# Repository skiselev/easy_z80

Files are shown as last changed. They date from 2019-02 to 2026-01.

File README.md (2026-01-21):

# Easy Z80
An easy to build Zilog Z80 based single board computer

## Table of Contents
* [Introduction](#introduction)
* [Specifications](#specifications)
* [Hardware Documentation](#hardware-documentation)
  * [Schematic and PCB Layout](#schematic-and-pcb-layout)
  * [Connectors and Jumpers](#connectors-and-jumpers)
  * [Bill of Materials](#bill-of-materials)
* [Firmware Documentation](#firmware-documentation)
  * [BIOS and OS](#bios-and-os)
  * [SPLD Fuse Map](#spld-fuse-map)
* [Release Notes](#release-notes)
  * [Changes](#changes)
  * [Known Issues](#known-issues)
  * [Wishlist](#wishlist)

## Introduction
My son Max asked me what it takes to build a computer, and whether or not he can design and build one himself. This project is our attempt to design and build a simple, easy to understand, yet capable single board computer.
It reuses the same memory paging mechanism I've implemented in Zeta SBC V2. It uses the Zilog Z80 SIO/O, Z80 CTC peripheral ICs, and implements daisy chain mode 2 interrupt configuration.

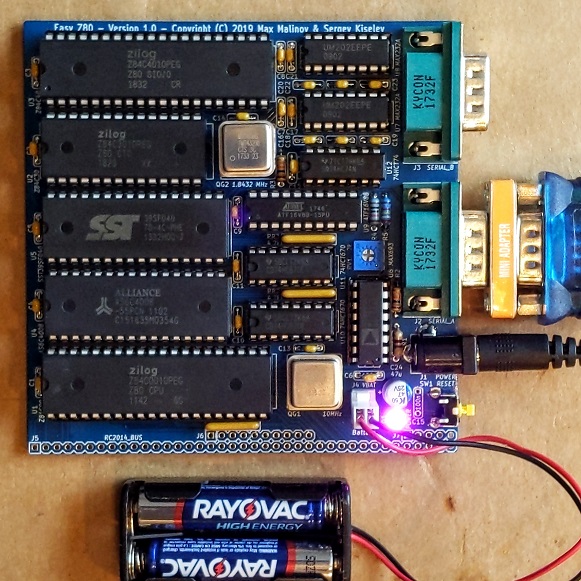
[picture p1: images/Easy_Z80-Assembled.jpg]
Easy Z80 PCB Rendering


## Specifications
* Processor: Zilog Z80 CPU (CMOS version - Z84C00)
* Memory: 512 KiB battery-backed SRAM, 512 KiB Flash ROM
* I/O:
  * Zilog Z80 CTC - Programmable timer used for periodic interrupts and (optionally) for generating UART clock
  * Zilog Z80 SIO - Dual channel serial interface, used for console and for connecting to other peripheral devices
* Bus: [RC2014](https://rc2014.co.uk/) compatible
* Microprocessor Supervisor:
  * Reset generation
  * SRAM battery backup
  * Power failure NMI
  * Watchdog (optional)

## Hardware Documentation

For the version 1.0 schematic, PCB layout, and bill of materials please refer to [tag v1.0](https://github.com/skiselev/easy_z80/tree/v1.0)

### Schematic and PCB Layout

[Schematic - Version 1.1](KiCad/Easy_Z80-Schematic-1.1.pdf)

[PCB Layout - Version 1.1](KiCad/Easy_Z80-Board-1.1.pdf)

### Connectors and Jumpers

#### J1 - Power
Connect regulated +5V power supply to this connector.

Pin                     | Signal Name | Description
----------------------- | ----------- | -----------
Tip (the inner contact)	| VCC         | Positive terminal - +5V
Barrel / sleeve	        | GND         | Negative terminal - ground

#### J2, J3 - Serial Channel A and Serial Channel B
Pin    | Signal Name | Description
------ | ----------- | -----------
1	     | DCD         |	Carrier Detect; Not used - Not connected on the SBC
2	     | RXA, RXB    |	Receive Data; Input to SBC
3	     | TXA, TXB    |	Transmit Data; Output from SBC
4	     | DTR         |	Data Terminal Ready; Not used - Not connected on the SBC
5	     | GND         |	Connected to the SBC GND signal
6	     | DSR         | Data Set Ready; Not used - Not connected on the SBC
7      |	RTSA, RTSB  | Request to Send; Output from SBC
8	     | CTSA, CTSB  | Clear to Send; Input to SBC
9	     | RI	         | Ring Indicator; Not used - Not connected on the SBC
Shield	| DE9 Shield	 | Connected to the SBC GND signal

#### J4 - NVRAM Battery
Connect 3V battery for SRAM backup to this connector.

**Important: If the SRAM battery backup is not desired, short J4 with a jumper. Do not leave this connector open.**

Pin | Signal Name | Description
--- | ----------- | -----------
1  	| VBAT        | Positive terminal - +3V
2   | GND         | Negative terminal - ground

#### J5, J6, J7 - RC2014 Bus
Pin   | Signal Name | Description         | Pin  | Signal Name | Description
----- | ----------- | ------------------- | ---- | ----------- | -----------
J5-1  | A15         | Address A15; Output |      |             |
J5-2  | A14         | Address A14; Output |      |             |
J5-3  | A13         | Address A13; Output |      |             |
J5-4  | A12         | Address A12; Output |      |             |
J5-5  | A11         | Address A11; Output |      |             |
J5-6  | A10         | Address A10; Output |      |             |
J5-7  | A9          | Address A9; Output  |      |             |
J5-8  | A8          | Address A8; Output  |      |             |
J5-9  | A7          | Address A7; Output  |      |             |
J5-10 | A6          | Address A6; Output  |      |             |
J5-11 | A5          | Address A5; Output  |      |             |
J5-12 | A4          | Address A4; Output  |      |             |
J5-13 | A3          | Address A3; Output  |      |             |
J5-14 | A2          | Address A2; Output  |      |             |
J5-15 | A1          | Address A1; Output  |      |             |
J5-16 | A0          | Address A0; Output  |      |             |
J5-17 | GND         | Ground              | J6-1 | GND         | Ground
J5-18 | VCC         | Power Supply - +5V  | J6-2 | VCC         | Power Supply - +5V
J5-19 | /M1         | Machine Cycle One; Output | J6-3| /RFSH | DRAM refresh; Output
J5-20 | /RESET      | Reset; Output       | J6-4 | N/C         | Not connected
J5-21 | CPU_CLK     | CPU Clock; Output   | J6-5 | UART_CLK    | UART Clock (1.8432 MHz); Output
J5-22 | /INT        | Interrupt; Input    | J6-6 | /BUSACK     | DMA Bus Acknowledge; Output
J5-23 | /MREQ       | Memory Request; Output | J6-7 | /HALT    | Halt; Output
J5-24 | /WR         | Write Request; Output | J6-8 | /BUSREQ   | DMA Bus Request; Input
J5-25 | /RD         | Read Request; Output | J6-9 | /WAIT      | Wait; Input
J5-26 | /IORQ       | Input/Output Request; Output | J6-10 | /NMI | Non-maskable Interrupt; Input
J5-27 | D0          | Data D0; Input/Output |    |             |
J5-28 | D1          | Data D1; Input/Output |    |             |
J5-29 | D2          | Data D2; Input/Output |    |             |
J5-30 | D3          | Data D3; Input/Output |    |             |
J5-31 | D4          | Data D4; Input/Output |    |             |
J5-32 | D5          | Data D5; Input/Output |    |             |
J5-33 | D6          | Data D6; Input/Output |    |             |
J5-34 | D7          | Data D7; Input/Output |    |             |
J5-35 | TXDA        | Channel A, Transmit Data; Output | J7-1 | TXDB | Channel B, Transmit Data; Output
J5-36 | RXDA        | Channel A, Receive Data; Input   | J7-2 | RXDB | Channel B, Receive Data; Input
J5-37 | USR1        | User Pin 1, Not connected | J7-3 | USR5  | User Pin 5, Not connected 
J5-38 | IEI         | Interrupt Enable Input  | J7-4 | USR6    | User Pin 6, Not connected 
J5-39 | IEO         | Interrupt Enable Output | J7-5 | USR7    | User Pin 7, Not connected 

#### JP1 - Serial Channel A Clock Select
Position        | Description
--------------- | -----------
*1-2 (default)* | 1.8432 MHz (115200 bps if using x16 mode)
2-3             | Programmable using CTC channel 0

#### JP2 - Serial Channel B Clock Select
Position        | Description
--------------- | -----------
*1-2 (default)* | 1.8432 MHz (115200 bps if using x16 mode)
2-3             | Programmable using CTC channel 1

### Bill of Materials

#### Version 1.1

[Easy Z80 project on Mouser.com](https://www.mouser.com/ProjectManager/ProjectDetail.aspx?AccessID=f16751cb33) - View and order all components except of the PCB.

[Easy Z80 project on OSH Park](https://oshpark.com/shared_projects/Rt7SBcRg) - View and order the PCB.

Component type     | Reference | Description                                 | Quantity | Possible sources and notes 
------------------ | --------- | ------------------------------------------- | -------- | --------------------------
PCB                |           | Easy Z80 PCB - Version 1.1                  | 1        | Refer to the [RetroBrew Computers Board Inventory](https://www.retrobrewcomputers.org/doku.php?id=boardinventory#minimal_8085_z80_single_board_computer) page for ordering information, or order from a PCB manufacturer of your choice using provided Gerber or KiCad files
Integrated Circuit | U1        | Z80 CPU, CMOS, 40 pin DIP - Z84C00xxPEG     | 1        | Mouser [692-Z84C0010PEG](https://www.mouser.com/ProductDetail/692-Z84C0010PEG)
Integrated Circuit | U2        | Z80 CTC, CMOS, 28 pin DIP - Z84C30xxPEG     | 1        | Mouser [692-Z84C3010PEG](https://www.mouser.com/ProductDetail/692-Z84C3010PEG)
Integrated Circuit | U3        | Z80 SIO/0, CMOS, 40 pin DIP - Z84C40xxPEG   | 1        | Mouser [692-Z84C4010PEG](https://www.mouser.com/ProductDetail/692-Z84C4010PEG)
Integrated Circuit | U4        | 512 KiB SRAM, 32 pin DIP - AS6C4008         | 1        | Mouser [913-AS6C4008-55PCN](https://www.mouser.com/ProductDetail/913-AS6C4008-55PCN)
Integrated Circuit | U5        | 512 KiB Flash ROM, 32 pin DIP - SST39SF040  | 1        | Mouser [804-39SF0407CPHE](https://www.mouser.com/ProductDetail/804-39SF0407CPHE)
Integrated Circuit | U6        | Microprocessor Supervisory Circuit - MAX693 | 1        | Mouser [584-ADM693ANZ](https://www.mouser.com/ProductDetail/584-ADM693ANZ); Possible alternatives: MAX693, LTC693, ADM691, MAX691, LTC691, ADM695, MAX695, LTC965, LTC1235
Integrated Circuit | U7, U8    | Dual RS-232 Driver/Receiver - MAX232A       | 2        | Mouser [595-TRS202EIN](https://www.mouser.com/ProductDetail/595-TRS202EIN/)
Integrated Circuit | U9        | Simple Programmable Logic Device - ATF16V8B | 1        | Mouser [556-AF16V8B15PU](https://www.mouser.com/ProductDetail/556-AF16V8B15PU)
Integrated Circuit | U10, U11  | 4-by-4 Register File - 74HC670              | 2        | Mouser [595-CD74HC670E](https://www.mouser.com/ProductDetail/595-CD74HC670E)
Integrated Circuit | U12       | Dual Flip Flop - 74HC74                     | 1        | Mouser [595-SN74HC74N](https://www.mouser.com/ProductDetail/595-SN74HC74N)
Oscillator         | QG1       | 10 MHz, CMOS oscillator, Half Can           | 1        | Mouser [774-MXO45HS-3C-10.0](https://www.mouser.com/ProductDetail/774-MXO45HS-3C-10.0)
Oscillator         | QG2       | 1.8432 MHz, CMOS oscillator, Half Can       | 1        | Mouser [774-MXO45HS-3C-1.8](https://www.mouser.com/ProductDetail/774-MXO45HS-3C-1.8)
LED                | D1        | 3 mm, green LED indicator                   | 1        | Mouser [859-LTL-4231N](https://www.mouser.com/ProductDetail/859-LTL-4231N)
Tactile Button     | SW1       | 6 mm tactile button, right angle            | 1        | Mouser [653-B3F-3152](https://www.mouser.com/ProductDetail/653-B3F-3152)
Connector          | J1        | DC Power Jack, 2mm                          | 1        | Mouser [806-KLDX-0202-A](https://www.mouser.com/ProductDetail/806-KLDX-0202-A)
Connector          | J2, J3    | Sub-D DE9M, Right Angle, PCB mount          | 2        | Mouser [806-K22X-E9P-N-99](https://www.mouser.com/ProductDetail/806-K22X-E9P-N-99)
Connector          | J4        | 2 Pin Header with Friction Lock             | 1        | Mouser [571-6404562](https://www.mouser.com/ProductDetail/571-6404562)
Pin Header         | J5 - J7   | 40x2 Pin Header, 2.54 mm Pitch, Right Angle | 1        | Mouser [571-9-103326-0](https://www.mouser.com/ProductDetail/571-9-103326-0)
Capacitor          | C1 - C14, C16 - C23  | 0.1 uF, MLCC, 5 mm Pitch         | 22       | Mouser [594-K104K15X7RF53H5](https://www.mouser.com/ProductDetail/594-K104K15X7RF53H5)
Capacitor          | C24       | 47 uF, 25V, Aluminum Organic Polymer        | 1        | Mouser [80-A750EK476M1EAAE40](https://www.mouser.com/ProductDetail/80-A750EK476M1EAAE40)
Resistor Array     | RN1 - RN3 | 4.7 k, bussed, 5 pin SIP                    | 3        | Mouser [652-4605X-AP1-472LF](https://www.mouser.com/ProductDetail/652-4605X-AP1-472LF)
Resistor Array     | RN4       | 4.7 k, bussed, 9 pin SIP                    | 1        | Mouser [652-4609X-AP1-472LF](https://www.mouser.com/ProductDetail/652-4609X-AP1-472LF)
Resistor           | R1        | 470 ohm, axial                              | 1        | Mouser [603-MFR-25FRF52-470R](https://www.mouser.com/ProductDetail/603-MFR-25FRF52-470R) 
Resistor           | R2 - R4   | 10 kohm, 1% tolerance, axial                | 3        | Mouser [603-MFR-25FRF5210K](https://www.mouser.com/ProductDetail/603-MFR-25FRF5210K)
Resistor           | R5        | 29.4 kohm, 1% tolerance, axial              | 1        | Mouser [603-MFR-25FBF52-29K4](https://www.mouser.com/ProductDetail/603-MFR-25FBF52-29K4)
Trimmer Resistor   | RV1       | 2 kohm, through hole                        | 1        | Mouser [652-3362P-1-202LF](https://www.mouser.com/ProductDetail/652-3362P-1-202LF)
IC Socket          | U1, U3    | 40 pin DIP                                  | 2        | Mouser [517-4840-6000-CP](https://www.mouser.com/ProductDetail/517-4840-6000-CP)
IC Socket          | U4, U5    | 32 pin DIP                                  | 2        | Mouser [517-4832-6000-CP](https://www.mouser.com/ProductDetail/517-4832-6000-CP)
IC Socket          | U2        | 28 pin DIP                                  | 1        | Mouser [517-4828-6000-CP](https://www.mouser.com/ProductDetail/517-4828-6000-CP)
IC Socket          | U9        | 20 pin DIP                                  | 1        | Mouser [517-4820-3000-CP](https://www.mouser.com/ProductDetail/517-4820-3000-CP)
IC Socket          | U6 - U8, U10, U11 | 16 pin DIP                          | 5        | Mouser [517-4816-3000-CP](https://www.mouser.com/ProductDetail/517-4816-3000-CP)
IC Socket          | U12       | 14 pin DIP                                  | 1        | Mouser [517-4814-3000-CP](https://www.mouser.com/ProductDetail/517-4814-3000-CP)
Oscillator Socket  | QG1, QG2  | 4 pin DIP, Half Can                         | 2        | Mouser [535-1108800](https://www.mouser.com/ProductDetail/535-1108800)

## Firmware Documentation

### BIOS and OS

Easy Z80 is supported by [RomWBW](https://github.com/wwarthen/RomWBW) [v2.9.1](https://github.com/wwarthen/RomWBW/releases/tag/v2.9.1) and later. RomWBW includes BIOS, CP/M-80 2.2, Z-System, and a collection of utilities. It also should be possible to run [FUZIX](https://github.com/EtchedPixels/FUZIX) on this board.

### SPLD Fuse Map

Easy Z80 uses an ATF16V8/GAL16V8 SPLD (U9) for address decode logic. The [SPLD fuse map](SPLD/easy_z80_no_wdog.jed) and the [SPLD source code](SPLD/easy_z80_no_wdog.pld) are provided in [SPLD](SPLD) directory of this repository.

## Release Notes

### Changes
* Version 1.1
  * Add pull-up resistors on the data bus (RN4 - 4.7k) to support Z80 interrupt mode 0
  * Use 74HC series instead of 74HCT
  * Remove C15
  * Use RN reference for resistor arrays instead of RR
  * Update silkscreen:
    * Make RN1 reference and value visible
    * Update silkscreen of headers footprints, so that JP1 and JP2 don't cover the traces
    * Add project URL to the bottom silkscreen
* Version 1.0
  * Initial version

### Known Issues
* Version 1.0
  * Top silkscreen: RR1 reference and value are not visible. It should read "RR1, 4.7k"
  * Bottom silkscreen on JP1 and JP2 covers the trace connections, so they are not easily visible
  * Bottom silkscreen: No project URL. Should be [github.com/skiselev/easy_z80](https://github.com/skiselev/easy_z80)
  * Board will not reset when C15 is populated. Workaround: Do not populate this capacitor
  * Schematic and top silkscreen: Use 74HC series instead of 74HCT
  
### Wishlist
* Version 1.0
  * Add pull-ups on the data bus to support extension boards that were not designed for Z80 interrupt mode 2

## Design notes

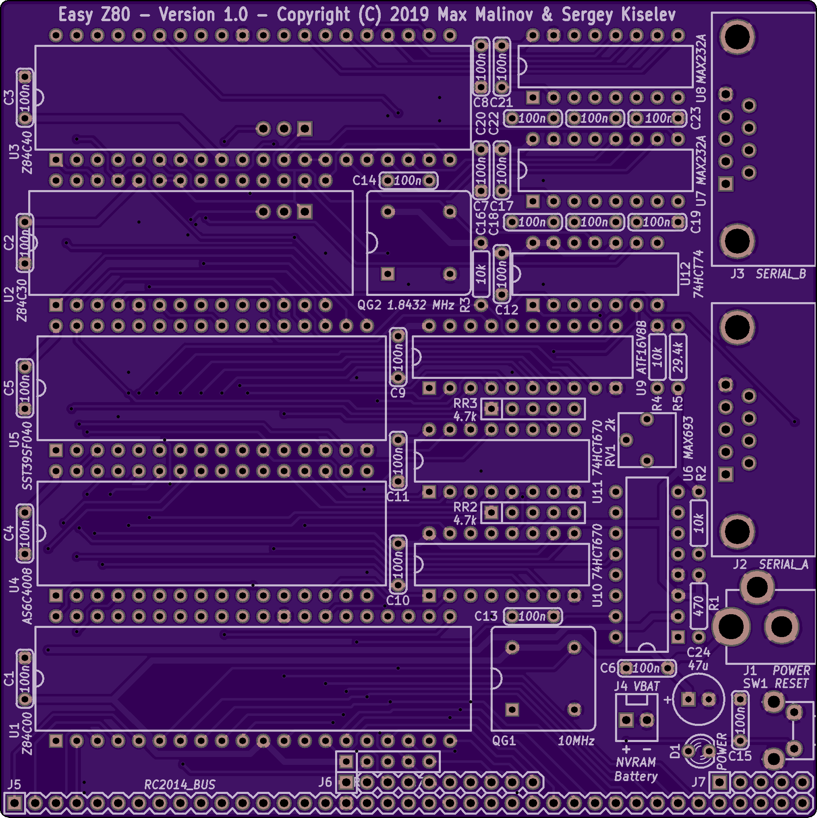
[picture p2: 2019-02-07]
images/PCB_Top_OshPark.png

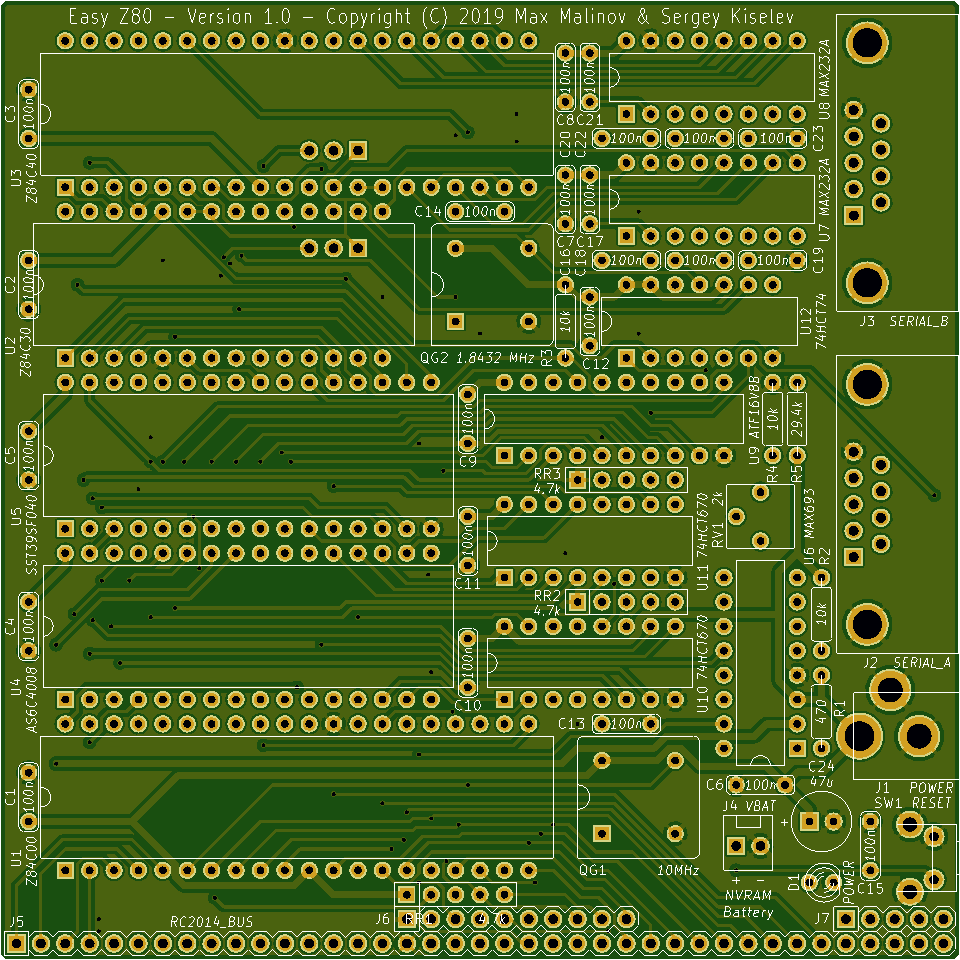
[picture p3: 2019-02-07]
images/PCB_Top_JLCPCB.png

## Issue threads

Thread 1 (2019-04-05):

74HC or 74HCT

EtchedPixels, 2019-04-05:
The BOM gives 74HCT part numbers against 74HC Mouser links ?

skiselev, 2019-04-05:
It doesn't really matter, either 74HC or 74HCT should work with CMOS Z84C00 CPU. If using NMOS Z80 CPU, I'd recommend using 74HCT.
The reason I've used 74HC in the Mouser BOM is that 74HCT670's are ridiculously expensive, and 74HC670 quite a bit cheaper.

EtchedPixels, 2019-04-05:
Ok thanks..

skiselev, 2019-04-05:
For the sake of consistency, I'll update the BOM. And for the next revision of the PCB, I'll also update the silkscreen.

skiselev, 2019-06-12:
The logic ICs are changed to 74HC series in version 1.1.
Thanks for the feedback!

Closed 2019-06-12.

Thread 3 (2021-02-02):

Hints for troubleshooting build?

spujadas, 2021-02-02:
Hi,

First of all, thanks for the great project, had a great time working through the design!

At this point, I’ve manufactured the PCB (version 1.1), purchased the components as per the BOM, soldered everything, programmed the Flash ROM with RomWBW (EZZ80_std.rom version 3.0.1) and the SPLD with the provided fuse map, and have a jumper across J4 (no SRAM battery for now).
Plugging the board in to a 5V source lights up the LED, I’m reading 5V and 0V on the relevant power pins of the chips, and my signal analyser is showing that the oscillators are up and running and that there appears to be some movement on the chips.
But connecting a serial terminal (115,200 baud, 8 data bits, 1 stop bit, no parity, no flow control) to the primary serial port shows absolutely nothing (the serial cable is tested as working fine with another project).

Would you have any hints as to how to approach troubleshooting the board to work out what I missed or did wrong?

Thanks very much!

skiselev, 2021-02-02:
Can you please try enabling RTS/CTS flow control in your terminal emulation software?

spujadas, 2021-02-02:
Thanks for the reply, changed to RTS/CTS flow control but made no difference unfortunately. (Also tried the other flow controls just in case.)

skiselev, 2021-02-02:
Next, I'd check the /RESET signal on the CPU (should be high) , activity on the control lines and address lines of the CPU, probably starting with /M1, /MREQ, /RD, A0, next check /ROM_CS signal. If all appear to be active, check SIO/2 chip select signal.

spujadas, 2021-02-03:
Thanks for your guidance.
The /RESET signal on the CPU was alternating between high for 1.376s and low for 43ms, but other than that I wasn’t seeing any activity on the CPU.
I realised that the CPU wasn’t receiving the clock signal (no activity whatsoever on pin 6). No idea why, especially considering that all the other chips were getting this signal.

Anyway, I soldered a wire to connect the oscillator to the CPU, and whilst I still wasn’t getting anything on the serial port, at the very least I started seeing some activity on the pins you mentioned (and the /RESET signal was stable at high)… for a few minutes, and then nothing again despite several resets.
I checked that the CPU was still working using another project, and confirmed it was indeed the case.

At this point, I’m suspecting poor PCB manufacturing or poor soldering on my part (even though nothing jumps out, the connections look fine both physically and electrically), so as fortunately I have 4 more Easy-Z80 PCBs (where I’ve confirmed that pin 6 of the CPU is indeed electrically connected to the output of the oscillator), I think I’ll probably redo everything from scratch.

Long story short, I’ll close this issue as it seems likely that something is actually physically wrong with the project on my end.
Thanks again Sergey for your quick replies and helpful suggestions!

Closed 2021-02-03.

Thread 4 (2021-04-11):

Doesn't work without watchdog chip MAX693

xrayer, 2021-04-11:
Hi,
I just finished my Easy Z80 board except I don't have MAX693 that is quite expansive and I don't need it. I flashed easy_z80_no_wdog.jed to PLD so I assume it's intended to run also without watchdog. But the board was dead. After some scoping around bus signals I see that data signals was quite messy and CS# signal of RAM was on unacceptable voltage level, neither L nor H. Then I found in schematics that this signal is passed through MAX693 so I made a wire jumper in the socket between pins 12-13 and viola, it boots :)

BTW do I need to recompile ROMWBW when I use different FlashROM chip (EN29F040A) that have different ID or will the FW detect it at runtime and writting will work?

skiselev, 2021-04-12:
Hi,

As the Bill of Materials suggests, MAX693 can be replaced with a cheaper [ADM693ANZ](https://www.mouser.com/ProductDetail/584-ADM693ANZ). Watchdog is not the only function of this IC. It also provides proper reset signal on power-on, and battery backup for SRAM (and that's why RAM CS signal goes through it). You can get by without the watchdog, and battery backup. But without the proper reset, the operation might be unreliable. So if you decide to omit MAX693/ADM693, you should use some another reset circuit, for example DS1233.

RomWBW itself does not write to the Flash ROM, so you don't need to recompile it.
[FLASH4](https://github.com/wwarthen/RomWBW/blob/master/Doc/Contrib/Flash4.txt) tool supports in-system Flash ROM programming. I don't see EN29F040A listed as one of the supported parts. You can try reaching to the author (see link above) and ask him about adding the support. Or better yet, add it yourself - and contribute to the project.

Thanks,
Sergey

xrayer, 2021-04-13:
Yes, I understand function of the WD also for reset circuit and SRAM bkup, but for now I can simply use reset push-button and have it powere by adapter. I should have some other spare supervisor/reset circuit... ADM693 looks better but currently sold out in local part supplier and for Mouser I'll wait to collect bigger BOM for the shipping. I also had problem with getting square oscillator, I used SMD part soldered on SO8 socket...

I think it would be just good idea to write a line about the needed jumper when WD not used in readme.md for other builders...

I'll have a look on ROMWBW, need to study a bit how to compile, what tool chains I need to install, etc...

BTW at boot it displays CPU clock 10MHz - seems to be hardcoded as I have CPU at 4MHz only. Does it use CPU freq. value for some internal timing code? As I have SIO on it's own 1,8xMHz oscillator console works normally.

Closed 2021-04-12.

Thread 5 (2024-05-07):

Can 74LSxxx be used as a replacement for 74HCTxxx/74HCxxx

ericzhang-debug, 2024-05-07:
hello, Can 74LSxxx be used as a replacement for 74HCTxxx/74HCxxx in this project? Can it work normally?

skiselev, 2024-05-08:
I think it will work.
A few notes:
- Don't mix 74HC with 74LS
- It's ok to mix 74HCT with 74LS
- Power consumption might go up a bit

Closed 2024-05-29.

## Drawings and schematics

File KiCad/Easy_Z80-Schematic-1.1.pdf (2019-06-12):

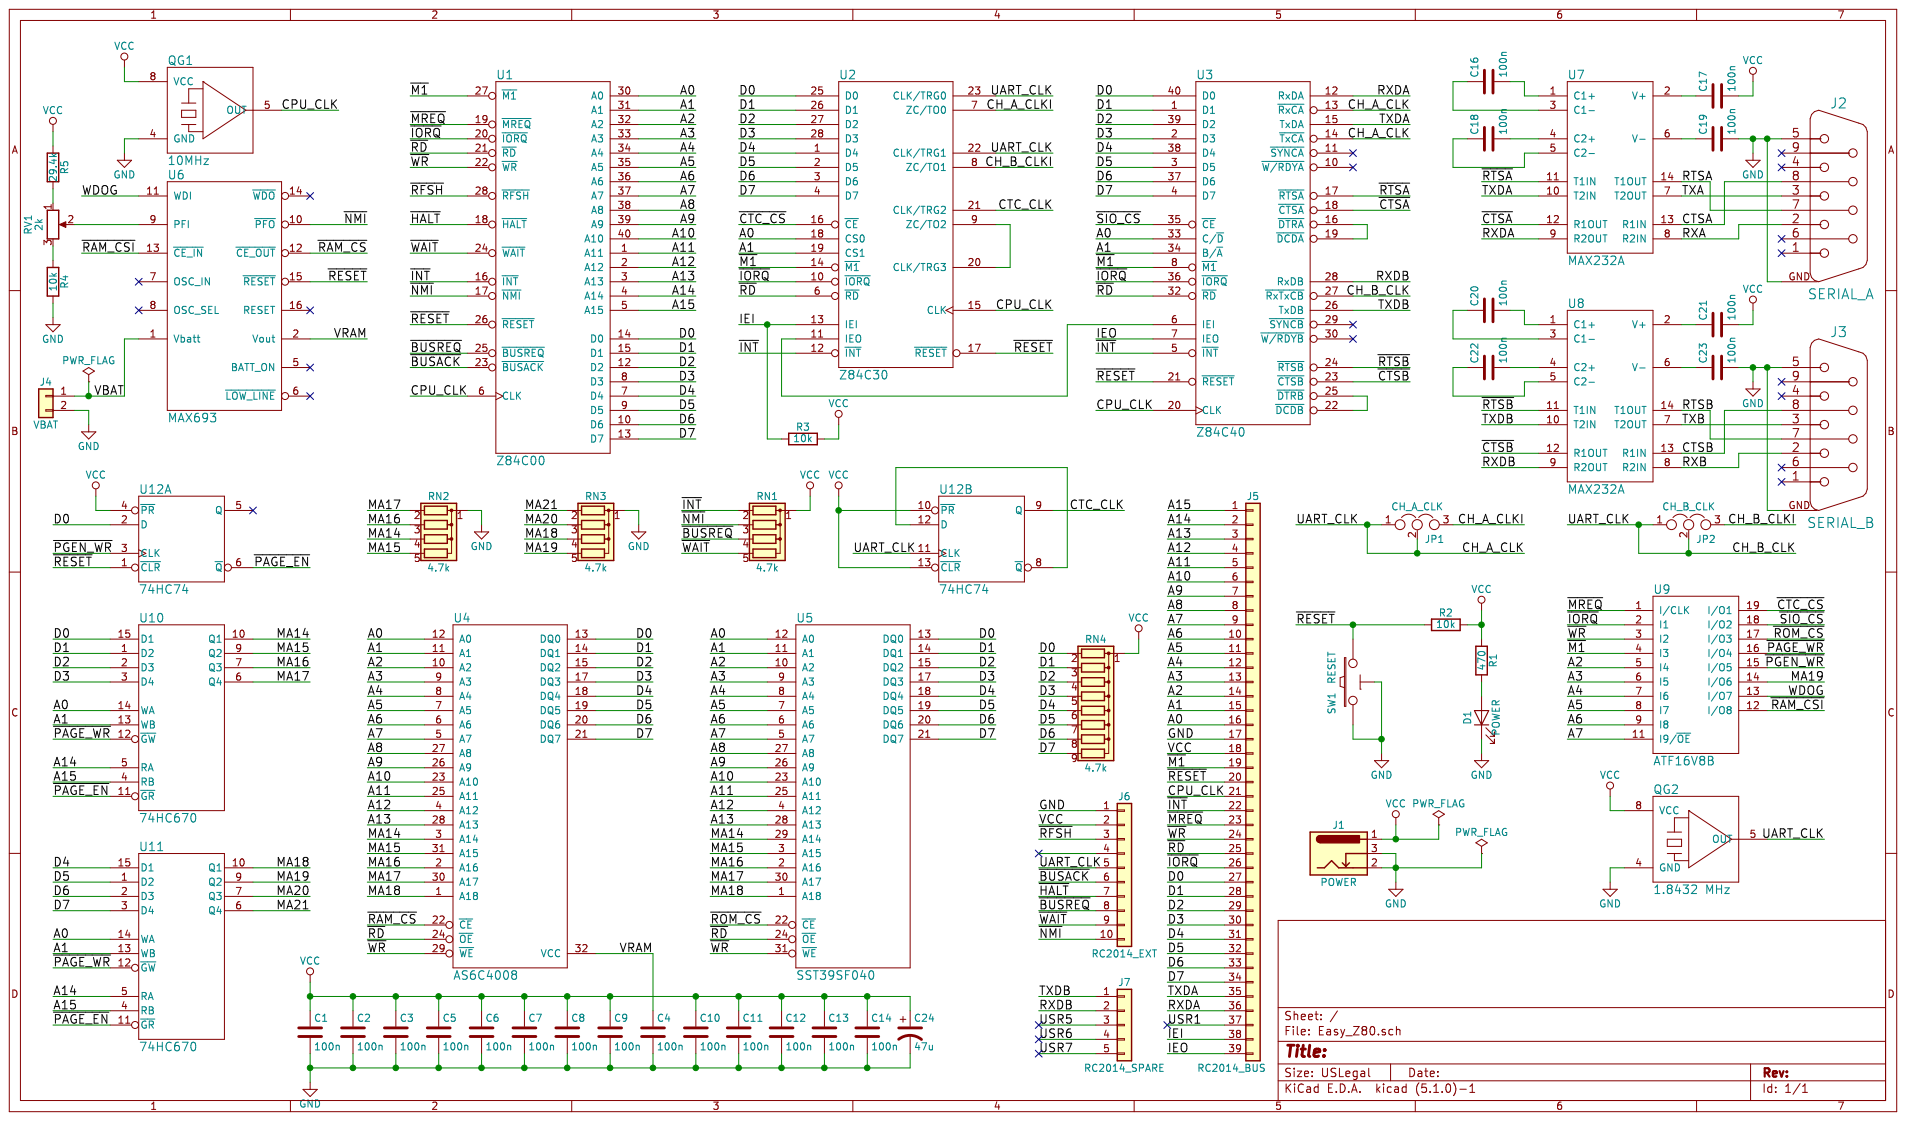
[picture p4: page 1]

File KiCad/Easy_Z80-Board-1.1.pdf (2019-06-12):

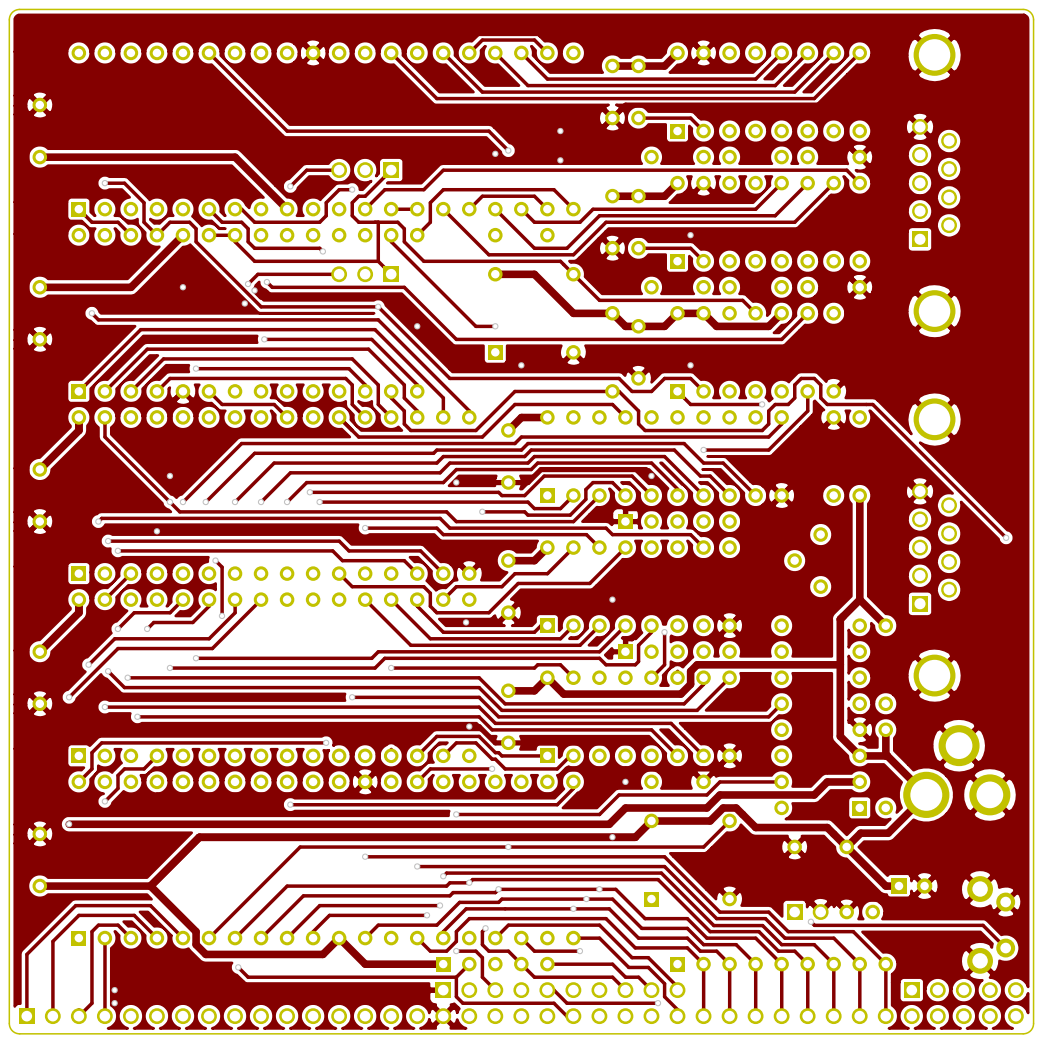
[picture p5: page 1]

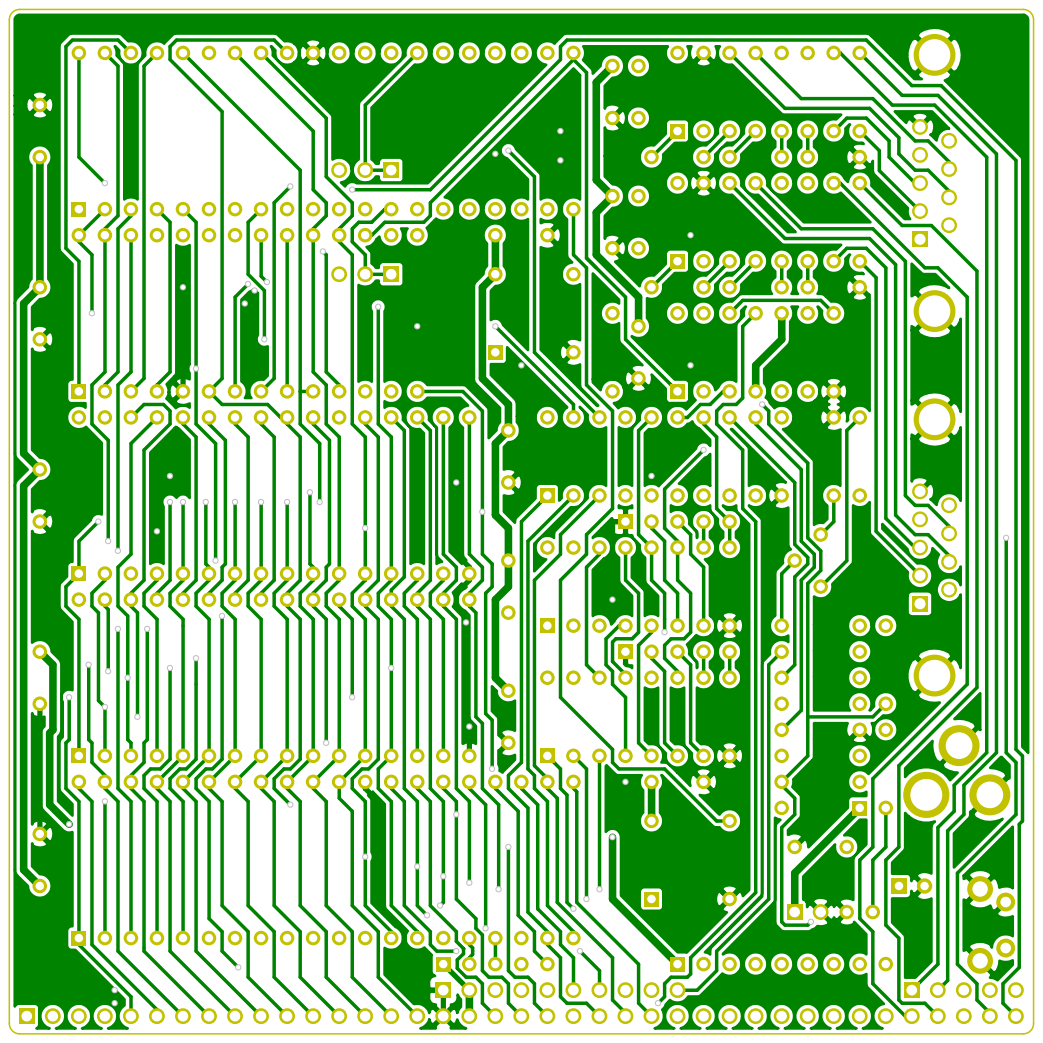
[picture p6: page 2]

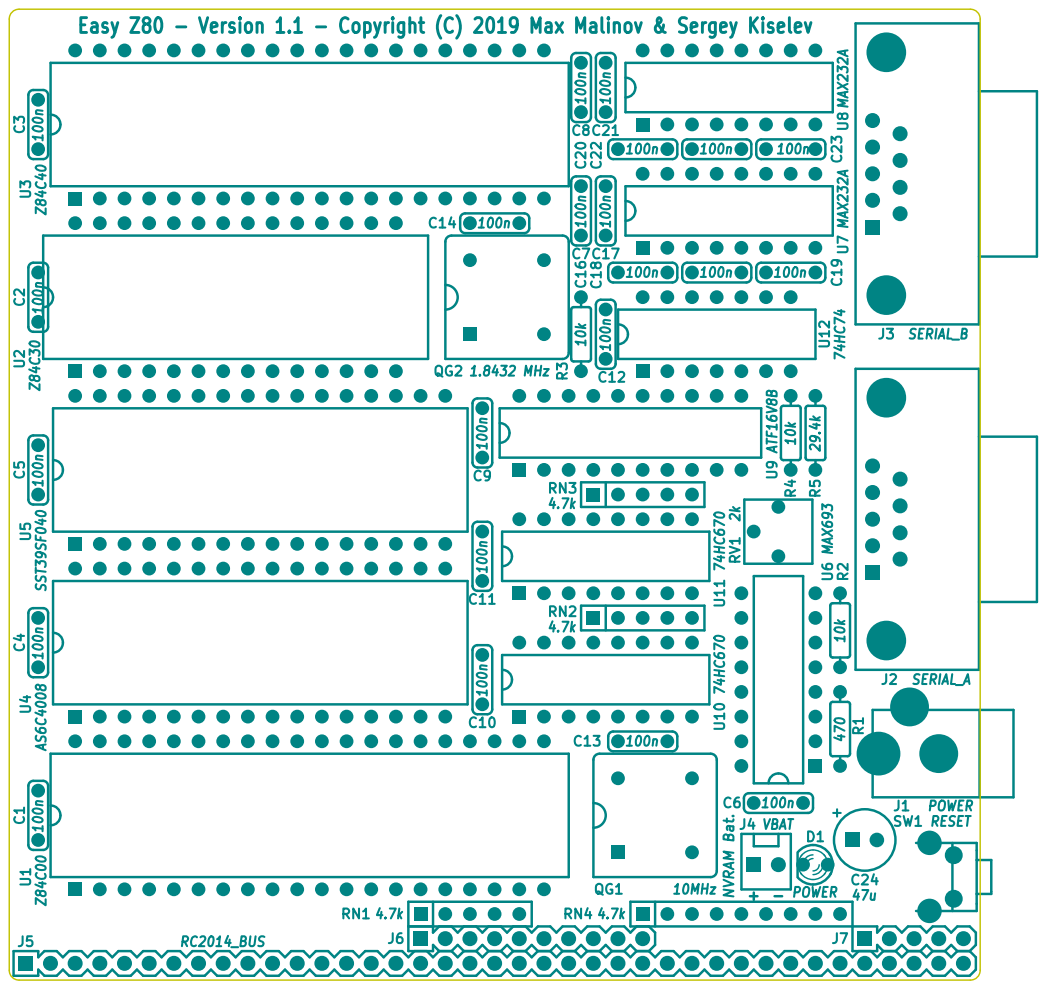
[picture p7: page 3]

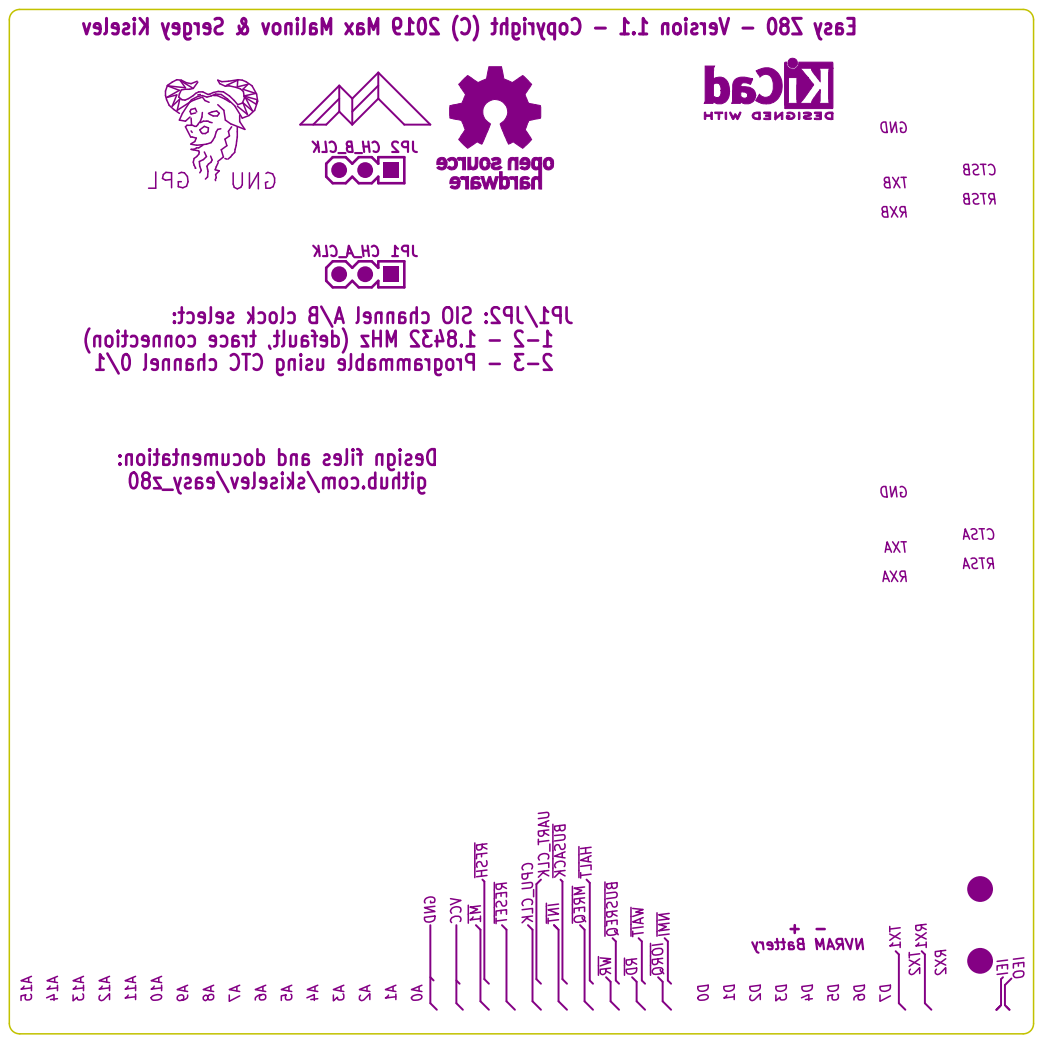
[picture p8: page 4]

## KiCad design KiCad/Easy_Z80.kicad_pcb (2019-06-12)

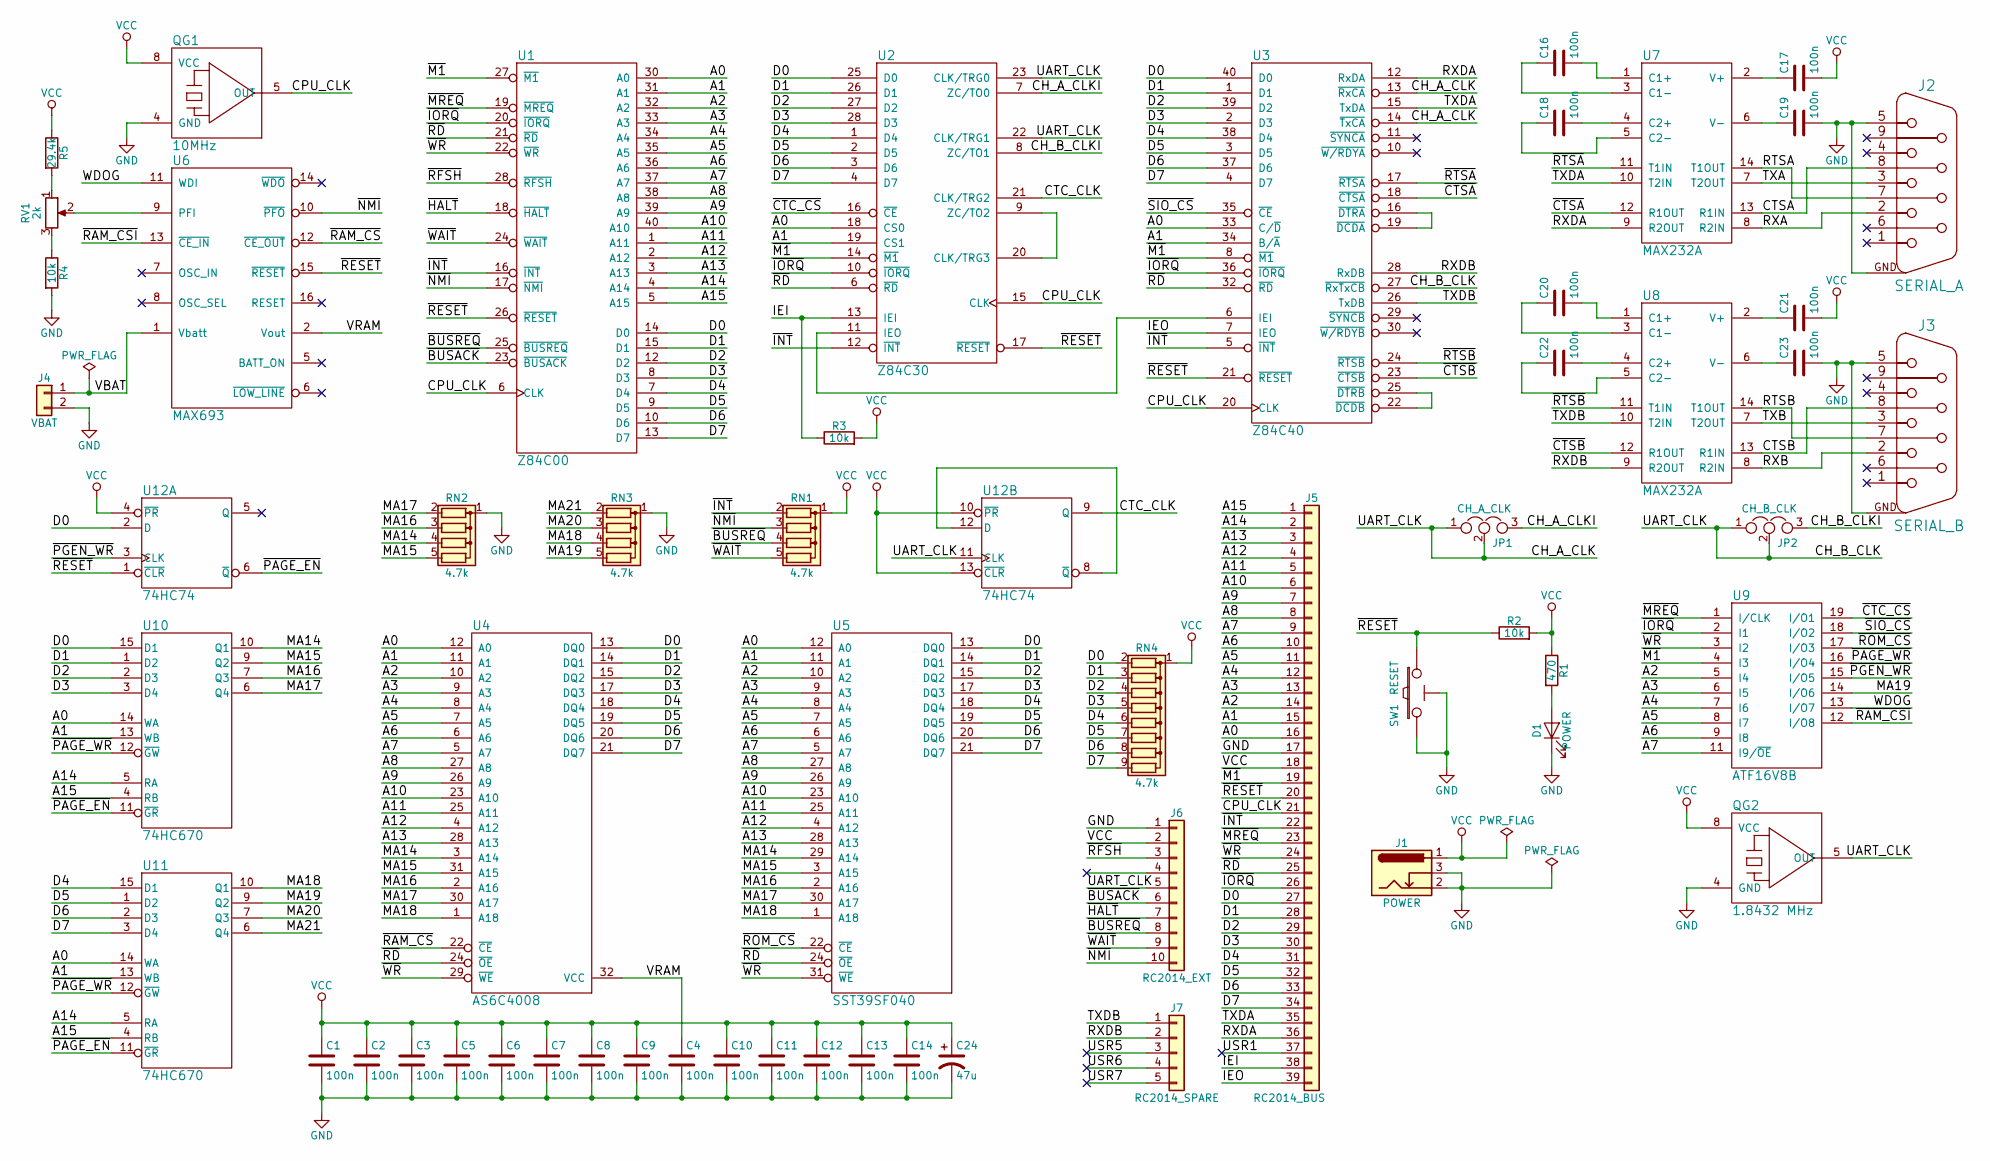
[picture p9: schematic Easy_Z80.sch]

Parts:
C1, C2, C3, C4, C5, C6, C7, C8, C9, C10, C11, C12, C13, C14, C16, C17, C18, C19, C20, C21, C22, C23: 100n; Cap_Cer_508
C24: 47u; Cap_Elec_Radial_6.3mm
D1: POWER; LED_3mm
J1: POWER; Conn_Power_Jack_Circular_Pads
J2: SERIAL_A; Conn_Dsub_DE9M
J3: SERIAL_B; Conn_Dsub_DE9M
J4: VBAT; Conn_Friction_Lock_2P_2.54mm
J5: RC2014_BUS; Conn_Pin_Header_39x1_2.54mm
J6: RC2014_EXT; Conn_Pin_Header_10x1_2.54mm
J7: RC2014_SPARE; Conn_Pin_Header_5x1_2.54mm
JP1: CH_A_CLK; Conn_Pin_Header_3x1_2.54mm
JP2: CH_B_CLK; Conn_Pin_Header_3x1_2.54mm
QG1: 10MHz; OSC_Half_Can_DIP8
QG2: 1.8432 MHz; OSC_Half_Can_DIP8
R1: 470; Res_762
R2, R3, R4: 10k; Res_762
R5: 29.4k; Res_762
RN1, RN2, RN3: 4.7k; Conn_SIL5
RN4: 4.7k; Conn_SIL9
RV1: 2k; Trimmer_Bourns_3362P
SW1: RESET; Switch_Tactile_6mm_Right
U1: Z84C00; IC_DIP40_600
U2: Z84C30; IC_DIP28_600
U3: Z84C40; IC_DIP40_600
U4: AS6C4008; IC_DIP32_600
U5: SST39SF040; IC_DIP32_600
U6: MAX693; IC_DIP16_300
U7, U8: MAX232A; IC_DIP16_300
U9: ATF16V8B; IC_DIP20_300
U10, U11: 74HC670; IC_DIP16_300
U12: 74HC74; IC_DIP14_300

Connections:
/A0: J5.16, U1.30 (A0), U2.18 (CS0), U3.33 (C/~D), U4.12 (A0), U5.12 (A0), U10.14 (WA), U11.14 (WA)
/A1: J5.15, U1.31 (A1), U2.19 (CS1), U3.34 (B/~A), U4.11 (A1), U5.11 (A1), U10.13 (WB), U11.13 (WB)
/A2: J5.14, U1.32 (A2), U4.10 (A2), U5.10 (A2), U9.5 (I4)
/A3: J5.13, U1.33 (A3), U4.9 (A3), U5.9 (A3), U9.6 (I5)
/A4: J5.12, U1.34 (A4), U4.8 (A4), U5.8 (A4), U9.7 (I6)
/A5: J5.11, U1.35 (A5), U4.7 (A5), U5.7 (A5), U9.8 (I7)
/A6: J5.10, U1.36 (A6), U4.6 (A6), U5.6 (A6), U9.9 (I8)
/A7: J5.9, U1.37 (A7), U4.5 (A7), U5.5 (A7), U9.11 (I9/~OE)
/A8: J5.8, U1.38 (A8), U4.27 (A8), U5.27 (A8)
/A9: J5.7, U1.39 (A9), U4.26 (A9), U5.26 (A9)
/A10: J5.6, U1.40 (A10), U4.23 (A10), U5.23 (A10)
/A11: J5.5, U1.1 (A11), U4.25 (A11), U5.25 (A11)
/A12: J5.4, U1.2 (A12), U4.4 (A12), U5.4 (A12)
/A13: J5.3, U1.3 (A13), U4.28 (A13), U5.28 (A13)
/A14: J5.2, U1.4 (A14), U10.5 (RA), U11.5 (RA)
/A15: J5.1, U1.5 (A15), U10.4 (RB), U11.4 (RB)
/CH_A_CLK: J6.5, JP1.1, JP1.2, JP2.1, JP2.2, QG2.5 (OUT), U2.22 (CLK/TRG1), U2.23 (CLK/TRG0), U3.13 (~RxCA), U3.14 (~TxCA), U3.27 (~RxTxCB), U12.11 (CLK)
/CH_A_CLKI: JP1.3, U2.7 (ZC/TO0)
/CH_B_CLKI: JP2.3, U2.8 (ZC/TO1)
/CPU_CLK: J5.21, QG1.5 (OUT), U1.6 (CLK), U2.15 (CLK), U3.20 (CLK)
/CTC_CLK: U2.21 (CLK/TRG2), U12.9 (Q)
/CTSA: J2.8, U7.13 (R1IN)
/CTSB: J3.8, U8.13 (R1IN)
/D0: J5.27, RN4.2 (R1), U1.14 (D0), U2.25 (D0), U3.40 (D0), U4.13 (DQ0), U5.13 (DQ0), U10.15 (D1), U12.2 (D)
/D1: J5.28, RN4.3 (R2), U1.15 (D1), U2.26 (D1), U3.1 (D1), U4.14 (DQ1), U5.14 (DQ1), U10.1 (D2)
/D2: J5.29, RN4.4 (R3), U1.12 (D2), U2.27 (D2), U3.39 (D2), U4.15 (DQ2), U5.15 (DQ2), U10.2 (D3)
/D3: J5.30, RN4.5 (R4), U1.8 (D3), U2.28 (D3), U3.2 (D3), U4.17 (DQ3), U5.17 (DQ3), U10.3 (D4)
/D4: J5.31, RN4.6 (R5), U1.7 (D4), U2.1 (D4), U3.38 (D4), U4.18 (DQ4), U5.18 (DQ4), U11.15 (D1)
/D5: J5.32, RN4.7 (R6), U1.9 (D5), U2.2 (D5), U3.3 (D5), U4.19 (DQ5), U5.19 (DQ5), U11.1 (D2)
/D6: J5.33, RN4.8 (R7), U1.10 (D6), U2.3 (D6), U3.37 (D6), U4.20 (DQ6), U5.20 (DQ6), U11.2 (D3)
/D7: J5.34, RN4.9 (R8), U1.13 (D7), U2.4 (D7), U3.4 (D7), U4.21 (DQ7), U5.21 (DQ7), U11.3 (D4)
/IEI: J5.38, R3.1, U2.13 (IEI)
/IEO: J5.39, U3.7 (IEO)
/MA14: RN2.4 (R3), U4.3 (A14), U5.29 (A14), U10.10 (Q1)
/MA15: RN2.5 (R4), U4.31 (A15), U5.3 (A15), U10.9 (Q2)
/MA16: RN2.3 (R2), U4.2 (A16), U5.2 (A16), U10.7 (Q3)
/MA17: RN2.2 (R1), U4.30 (A17), U5.30 (A17), U10.6 (Q4)
/MA18: RN3.4 (R3), U4.1 (A18), U5.1 (A18), U11.10 (Q1)
/MA19: RN3.5 (R4), U9.14 (I/O6), U11.9 (Q2)
/MA20: RN3.3 (R2), U11.7 (Q3)
/MA21: RN3.2 (R1), U11.6 (Q4)
/RTSA: J2.7, U7.14 (T1OUT)
/RTSB: J3.7, U8.14 (T1OUT)
/RXA: J2.2, U7.8 (R2IN)
/RXB: J3.2, U8.8 (R2IN)
/RXDA: J5.36, U3.12 (RxDA), U7.9 (R2OUT)
/RXDB: J7.2, U3.28 (RxDB), U8.9 (R2OUT)
/TXA: J2.3, U7.7 (T2OUT)
/TXB: J3.3, U8.7 (T2OUT)
/TXDA: J5.35, U3.15 (TxDA), U7.10 (T2IN)
/TXDB: J7.1, U3.26 (TxDB), U8.10 (T2IN)
/USR1: J5.37
/USR5: J7.3
/USR6: J7.4
/USR7: J7.5
/VBAT: J4.1, U6.1 (Vbatt)
/VRAM: C4.1, U4.32 (VCC), U6.2 (Vout)
/WDOG: U6.11 (WDI), U9.13 (I/O7)
/~BUSACK: J6.6, U1.23 (~BUSACK)
/~BUSREQ: J6.8, RN1.4 (R3), U1.25 (~BUSREQ)
/~CTC_CS: U2.16 (~CE), U9.19 (I/O1)
/~CTSA: U3.18 (~CTSA), U7.12 (R1OUT)
/~CTSB: U3.23 (~CTSB), U8.12 (R1OUT)
/~HALT: J6.7, U1.18 (~HALT)
/~INT: J5.22, RN1.2 (R1), U1.16 (~INT), U2.12 (~INT), U3.5 (~INT)
/~IORQ: J5.26, U1.20 (~IORQ), U2.10 (~IORQ), U3.36 (~IORQ), U9.2 (I1)
/~M1: J5.19, U1.27 (~M1), U2.14 (~M1), U3.8 (~M1), U9.4 (I3)
/~MREQ: J5.23, U1.19 (~MREQ), U9.1 (I/CLK)
/~NMI: J6.10, RN1.3 (R2), U1.17 (~NMI), U6.10 (~PFO)
/~PAGE_EN: U10.11 (~GR), U11.11 (~GR), U12.6 (~Q)
/~PAGE_WR: U9.16 (I/O4), U10.12 (~GW), U11.12 (~GW)
/~PGEN_WR: U9.15 (I/O5), U12.3 (CLK)
/~RAM_CS: U4.22 (~CE), U6.12 (~CE_OUT)
/~RAM_CSI: U6.13 (~CE_IN), U9.12 (I/O8)
/~RD: J5.25, U1.21 (~RD), U2.6 (~RD), U3.32 (~RD), U4.24 (~OE), U5.24 (~OE)
/~RESET: J5.20, R2.1, SW1.1, U1.26 (~RESET), U2.17 (~RESET), U3.21 (~RESET), U6.15 (~RESET), U12.1 (~CLR)
/~RFSH: J6.3, U1.28 (~RFSH)
/~ROM_CS: U5.22 (~CE), U9.17 (I/O3)
/~RTSA: U3.17 (~RTSA), U7.11 (T1IN)
/~RTSB: U3.24 (~RTSB), U8.11 (T1IN)
/~SIO_CS: U3.35 (~CE), U9.18 (I/O2)
/~WAIT: J6.9, RN1.5 (R4), U1.24 (~WAIT)
/~WR: J5.24, U1.22 (~WR), U4.29 (~WE), U5.31 (~WE), U9.3 (I2)
GND: C1.2, C2.2, C3.2, C4.2, C5.2, C6.2, C7.2, C8.2, C9.2, C10.2, C11.2, C12.2, C13.2, C14.2, C19.2, C23.2, C24.2, D1.1 (K), J1.2, J1.3, J2.5, J2.GND, J3.5, J3.GND, J4.2, J5.17, J6.1, QG1.4 (GND), QG2.4 (GND), R4.2, RN2.1 (common), RN3.1 (common), SW1.2, SW1.GND, U1.29 (GND), U2.5 (GND), U3.31 (GND), U4.16 (GND), U5.16 (GND), U6.4 (GND), U7.15 (GND), U8.15 (GND), U9.10 (GND), U10.8 (GND), U11.8 (GND), U12.7 (GND)
unnamed: C16.1, U7.3 (C1-)
unnamed: C16.2, U7.1 (C1+)
unnamed: C17.1, U7.2 (V+)
unnamed: C18.1, U7.5 (C2-)
unnamed: C18.2, U7.4 (C2+)
unnamed: C19.1, U7.6 (V-)
unnamed: C20.1, U8.3 (C1-)
unnamed: C20.2, U8.1 (C1+)
unnamed: C21.1, U8.2 (V+)
unnamed: C22.1, U8.5 (C2-)
unnamed: C22.2, U8.4 (C2+)
unnamed: C23.1, U8.6 (V-)
unnamed: D1.2 (A), R1.2
unnamed: R4.1, RV1.3
unnamed: R5.2, RV1.1
unnamed: RV1.2, U6.9 (PFI)
unnamed: U2.11 (IEO), U3.6 (IEI)
unnamed: U2.9 (ZC/TO2), U2.20 (CLK/TRG3)
unnamed: U3.16 (~DTRA), U3.19 (~DCDA)
unnamed: U3.22 (~DCDB), U3.25 (~DTRB)
unnamed: U12.8 (~Q), U12.12 (D)
VCC: C1.1, C2.1, C3.1, C5.1, C6.1, C7.1, C8.1, C9.1, C10.1, C11.1, C12.1, C13.1, C14.1, C17.2, C21.2, C24.1, J1.1, J5.18, J6.2, QG1.8 (VCC), QG2.8 (VCC), R1.1, R2.2, R3.2, R5.1, RN1.1 (common), RN4.1 (common), U1.11 (VCC), U2.24 (VCC), U3.9 (VCC), U5.32 (VCC), U6.3 (VCC), U7.16 (VCC), U8.16 (VCC), U9.20 (VCC), U10.16 (VCC), U11.16 (VCC), U12.4 (~PR), U12.10 (~PR), U12.13 (~CLR), U12.14 (VCC)

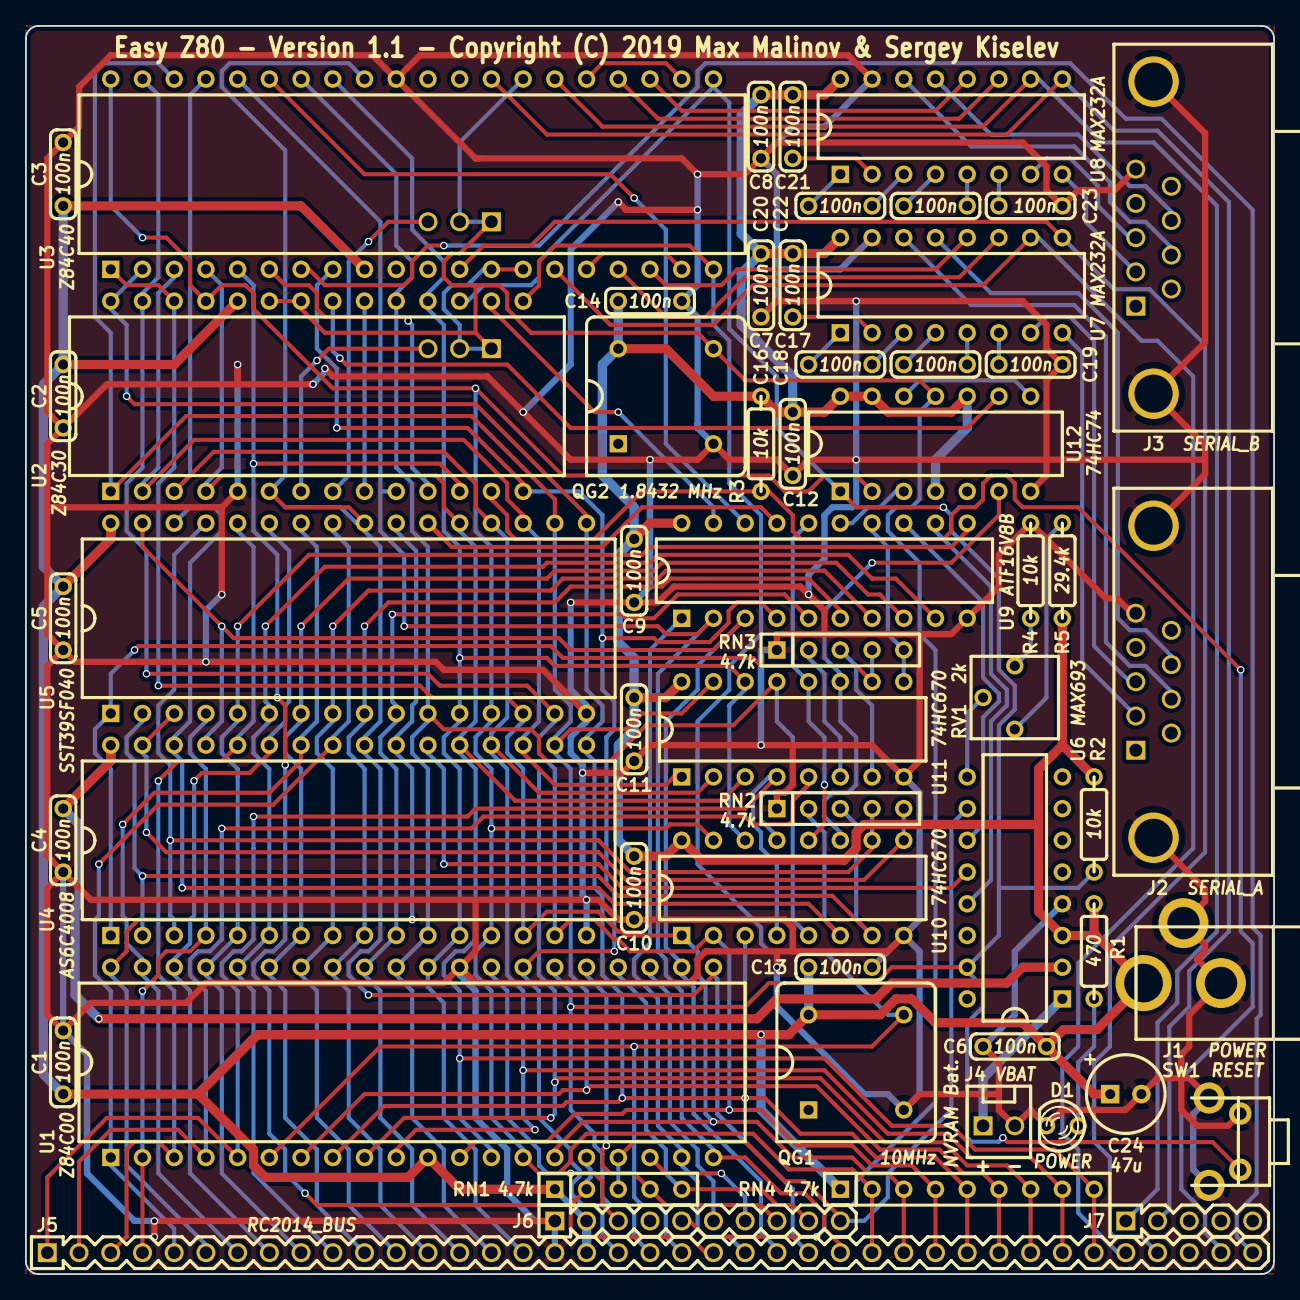
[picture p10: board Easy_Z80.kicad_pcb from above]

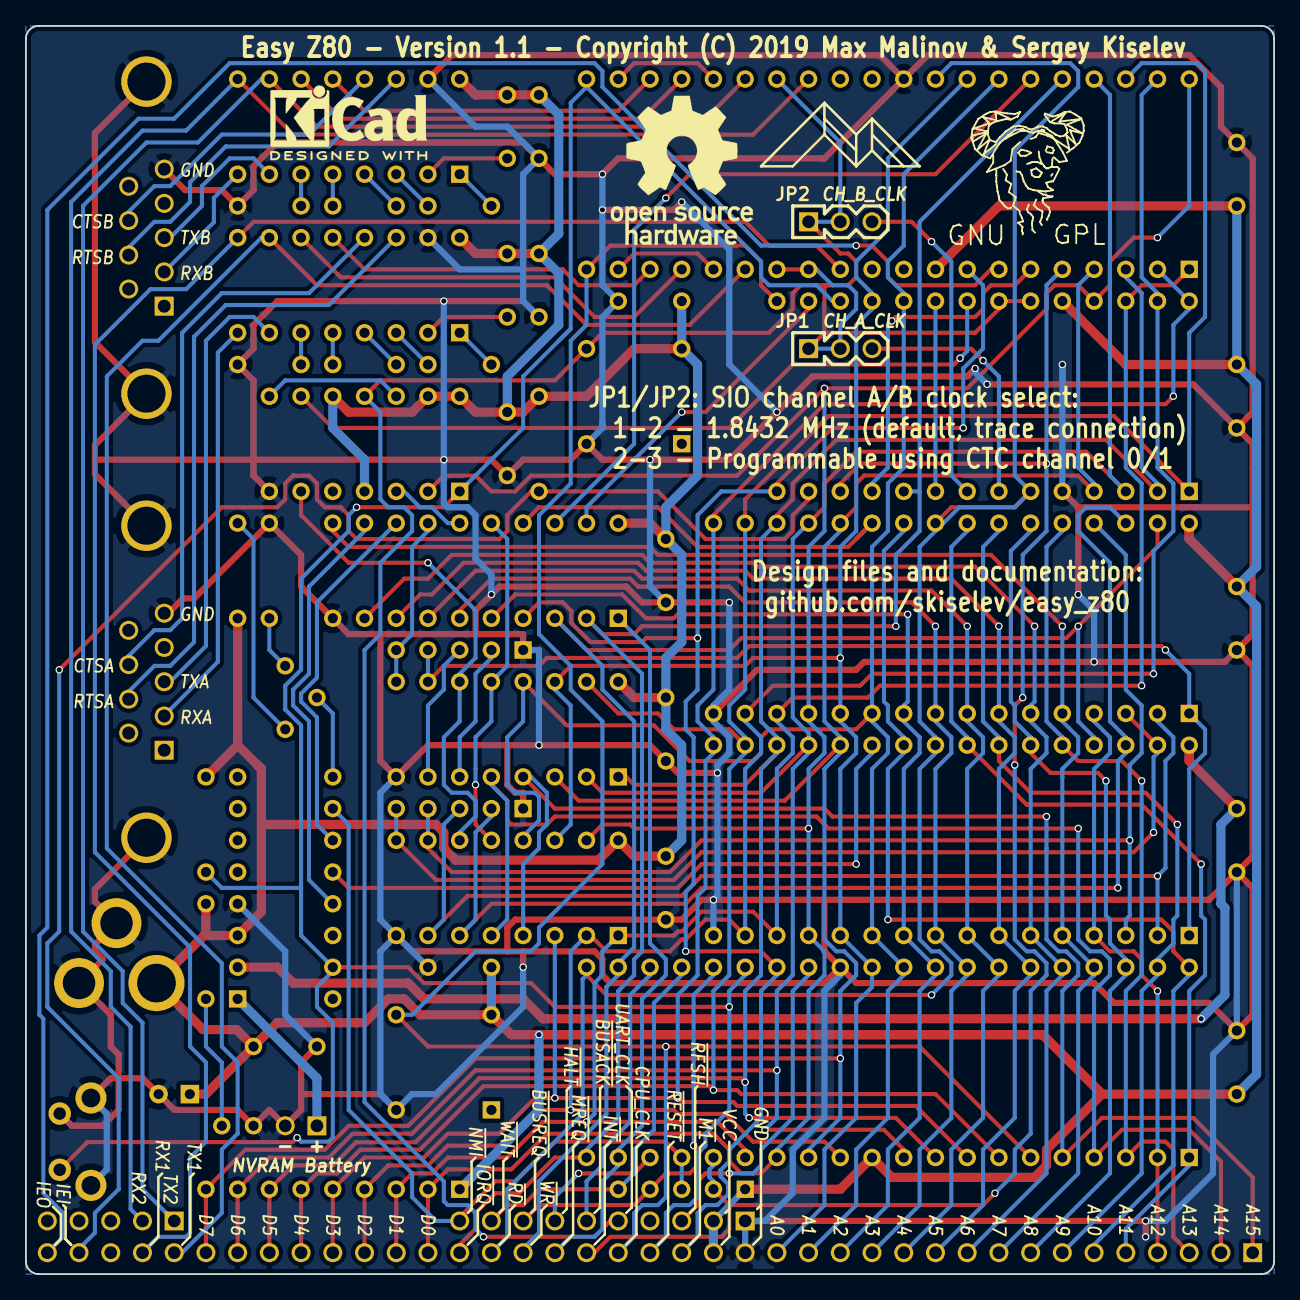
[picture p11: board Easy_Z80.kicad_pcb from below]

Board: 2 copper layers, 99.9 x 99.9 mm, 58 parts (2 on the bottom side), 102 nets.

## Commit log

2019-02-07 README: BOM: Fix quantities; use 1% resistors
    Fix the quantity of 470 ohm resistors, 10 kohm resistors, and 14 pin DIP sockets
    Use 1% resistors to reduce the number of different parts
2019-02-07 README: Add connectors documentation
2019-02-07 README: Add PCB rendering, schematic and board layout links
2019-02-07 Add KiCad, Gerber and Documentation
    [Easy_Z80-B.Cu.gbr, Easy_Z80-B.Mask.gbr, Easy_Z80-B.SilkS.gbr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]
2019-02-07 Add resized PCB rendering
2019-02-07 Update resized PCB rendering
2019-02-07 Add SPLD fuse maps
2019-02-15 PCB: Silkscreen fixes
    [Easy_Z80.kicad_pcb]
2019-02-26 SPLD: Add fusemap without watchdog
2019-02-27 SPLD: fix pin mapping
2019-02-27 README: Replace PCB rendering with the board photo; Describe C15 reset issue.
2019-02-27 Add a photo of the assembled board
2019-02-27 Update the photo of the assembled board
2019-03-05 README: Clarify peripherals and interrupt mode
2019-03-07 SPLD: Move watchdog to 0x6C-0x6F to avoid conflict with RC2014 secondary SIO board
2019-03-07 SPLD: Update fusemaps with the previous PLD change
2019-06-12 KiCad: Replace files with version 1.1
    [Easy_Z80.kicad_pcb, Easy_Z80.sch]
2019-06-12 Gerber: Replace files with version 1.1
    [Easy_Z80-B.Cu.gbr, Easy_Z80-B_Cu.gbr, Easy_Z80-B_Mask.gbr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]
2019-06-12 README: BOM and Changes updates for version 1.1
2019-06-12 README: Update BOM version 1.1
2019-06-13 README: BOM - PCB version is 1.1
2019-07-23 README: Add a note on the J4 connector
2020-06-30 README.md: fix U3 # of pins and link to JEDEC file
    The SIO is a 40 pin DIP. There are two JEDEC files, w/ and w/o watchdog.
    Link to the one w/o watchdog support.

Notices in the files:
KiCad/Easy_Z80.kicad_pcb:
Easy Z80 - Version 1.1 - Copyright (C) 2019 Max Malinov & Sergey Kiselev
